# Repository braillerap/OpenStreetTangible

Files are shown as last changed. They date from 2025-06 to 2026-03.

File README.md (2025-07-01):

# OpenStreetTangible
OpenStreetTangible is a demonstration of what's possible in terms of accessible public transportation maps using OpenStreetTouch software, BrailleRAP, and various digital fabrication tools.

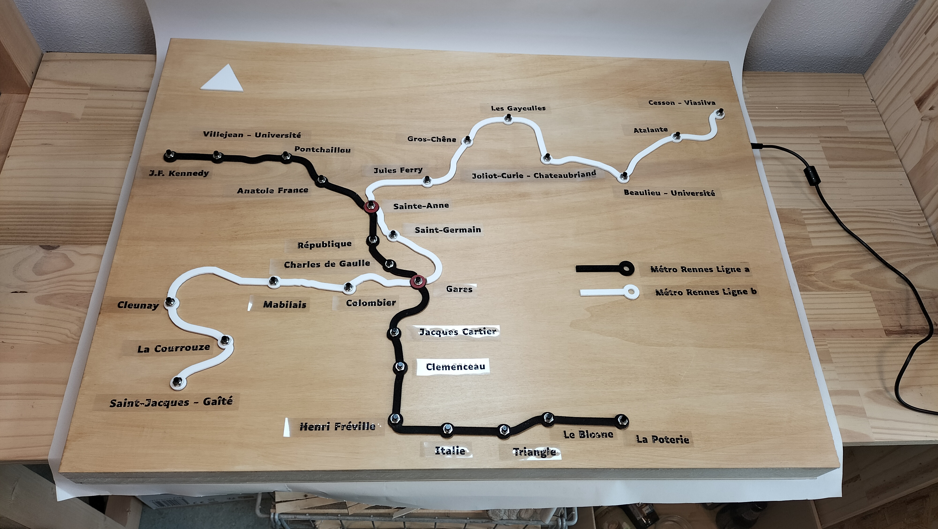
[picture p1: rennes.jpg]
Tangible map of Rennes Subway


It's a tactile, talking metro map of the city of Rennes in France, Britanny, designed for people with visual impairments.

To build this prototype, we used  [OpenStreetTouch](https://github.com/braillerap/OpenStreetTouch/releases) software to extract public transportation data and a [BrailleRAP](https://github.com/braillerap) to emboss stickers in Braille.

## Building manual
The building manual is available here [https://openstreettangible.readthedocs.io/en/latest/](https://openstreettangible.readthedocs.io/en/latest/)

Translations are availables here :

**en** 

**fr** 

## Contributions

### Translation
If you need the building manual in your locale language, we will be happy to add a new translation. Translation files are hosted on codeberg community translation platform and can be updated by anyone [weblate host on codeberg](https://translate.codeberg.org/engage/openstreettangible_buildingmanual/) for more information.

<a href="https://translate.codeberg.org/engage/openstreettangible_buildingmanual/">
Translation status
</a>

### New cities 
Feel free to open issues or pull requests ! We will be happy to review and merge your changes, especialy if you want to build a tangible transport map of your city.

## Funding

This project is funded through [NGI0 Entrust](https://nlnet.nl/entrust), a fund established by [NLnet](https://nlnet.nl) with financial support from the European Commission's [Next Generation Internet](https://ngi.eu) program. Learn more at the [NLnet project page](https://nlnet.nl/project/BrailleRAP).

[NLnet foundation logo](https://nlnet.nl)
[NGI Zero Logo](https://nlnet.nl/entrust)

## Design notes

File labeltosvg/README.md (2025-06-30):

# LABELTOSVG

This python script aim to build svg files suitables to make printed label stickers embossed with Braille on a BrailleRAP.

## Installation

you will need a python virtual env and install some python dependencies

```
python -m venv venv
source ./venv/bin/activate
pip install -r requirement.txt
```

## usage

To generate svg files for printer and BrailleRAP you will need a text files generated by [OpenStreetTouch](https://github.com/braillerap/OpenStreetTouch). for exemple here is the labels file for the Rennes subway map.

```
Métro Rennes Ligne a Direction Rennes (J.F. Kennedy) :
     La Poterie
     Le Blosne
     Triangle
     Italie
     Henri Fréville
     Clemenceau
     Jacques Cartier
  *  Gares
     Charles de Gaulle
     République
  *  Sainte-Anne
     Anatole France
     Pontchaillou
     Villejean - Université
     J.F. Kennedy

Métro Rennes Ligne b Direction Cesson-Sévigné (Viasilva) :
     Saint-Jacques - Gaîté
     La Courrouze
     Cleunay
     Mabilais
     Colombier
  *  Gares
     Saint-Germain
  *  Sainte-Anne
     Jules Ferry
     Gros-Chêne
     Les Gayeulles
     Joliot-Curie - Chateaubriand
     Beaulieu - Université
     Atalante
     Cesson - Viasilva

```
to generate svg files use the command :
```
python file2label.py <label txt file>
```

## Configuration
The script take account of the offset between our BraileRAP XL and a laser printer. During our cession, it appear that the BrailleRAP XL is very precise and reliable, the laser printer is not very accurate.

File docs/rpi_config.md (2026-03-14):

## Configuration du Raspberry PI 5
### Création de l'image système

Avec l'outil [Raspberry Pi Imager](https://www.raspberrypi.com/software/) installer la dernière version de **Raspberry PI OS** en version **lite** sur une carte SD.

vous devez activer une installation personnalisée avec les options suivantes

* Nom d'hote **subwaymap**
* creation d'un utilisateur **tactilmap** avec un mot de passe.
* activation de **ssh**.

```{note}
Pour terminer l'installation, vous aurez besoin de vous connecter au Raspberry PI par le réseau. De manière générale nous réalisons cette opération en connectant un câble ethernet, si vous souhaitez connecter le raspberry pi en wifi, vous devez configurer le wifi avant l'installation
```

Une fois toutes les options configurées, vous pouvez lancer la création de l'image sur la carte SD.

### Installation du système

* Connecter la carte shapeless_rp2040_40keys sur le Raspberry Pi avec un câble micro USB.
* Connecter le Raspberry Pi au réseau ethernet si besoin
* Brancher le câble USB micro d'alimentation du Raspberry PI
* Brancher la sortie audio du Raspberry PI sur un système audio avec un câble jack.

Une fois le Raspberry PI démarré, connectez-vous au Raspberry PI en ouvrant une console et en utilisant la commande :
```
ssh tactilmap@subwaymap.local
```
Le Raspberry PI vous demande alors le mot de passe associé au compte **tactilmap**. Le mot de passe a été configuré au moment de la création de l'image du système.

Ensuite à l'aide de l'outil **raspi_config** étendre la partition à l'ensemble de la carte SD et redémarrer le raspberry PI.
```
sudo raspi_config
```

Le Raspbery PI est désormais prêt pour l'installation des logiciels necessaires pour l'utilisation avec la carte tactile.

### Installation des logiciels

Connectez-vous au Raspberry PI :
```
ssh tactilmap@subwaymap.local
```

Installer les logiciels avec les commandes :
```
sudo apt update
sudo apt upgrade
sudo apt install git nano
sudo apt install cmake build-essential python3-dev
sudo apt install libportaudio2 libportaudiocpp0 portaudio19-dev

```

Installer la synthèse vocale **espeack-ng**
```
sudo apt install espeak-ng
```

### Carte Son
Le Raspberry PI 5 ne possède plus de sortie son au format JACK 3.5. Nous avons utilisé une carte son [Adafruit I2S - UDA1334A](https://learn.adafruit.com/adafruit-i2s-stereo-decoder-uda1334a). La qualité sonore est grandement améliorée par rapport à la carte son native des Raspberry 3 ou 4.

### Installation du logiciel speakerkeyboard

Le logiciel [speakerkeyboard](https://github.com/crocsg/speakerkeyboard) permet de déclencher la lecture d'un message en synthèse vocale lors de l'appui sur une touche du clavier. En utilisant la carte **shapeless_rp2040_40keys** il est possible de simuler l'appui sur une touche d'un clavier en appuyant sur un des boutons de la carte tactile.

```
cd /home/tactilmap
git clone https://github.com/crocsg/speakerkeyboard.git
cd speakerkeyboard
python -m venv venv
source ./venv/bin/activate
pip install -r requirement.txt
```

Le logiciel est utilisable uniquement en mode **root** dans la mesure ou nous utilisons le module python **keyboard** pour intercepter les évenements clavier.

Pour lancer le logiciel
```
sudo bash
cd /home/tactilmap/speakerkeyboard
source ./venv/bin/activate
python kspeaker.py
```

### Configurer les noms des stations

Pour réaliser la configuration, les boutons de la carte tactile doivent être branchés sur la carte **shapeless_rp2040_40keys** et la carte **shapeless_rp2040_40keys** doit être reliée en usb sur le Raspberry PI.

Lancer le logiciel
```
sudo bash
source ./venv/bin/activate
python kspeaker.py
```

Lors de l'appui sur un bouton de la carte tactile, le logiciel affiche le **code clavier**, le texte associé. Si un texte est associé à la touche, la synthèse vocale se déclenche et lit le texte en audio.

Pour configurer un message, arreter le logiciel avec `CTRL-C`, vous devez ensuite éditer le fichier **kspeaker.json** pour entrer le **code clavier** et le texte associé dans la section **messages**.

Le fichier **configuration.json** pour la carte tactile du métro de Rennes est donné ici a titre d'exemple.
```
{
    "device": "",
    "speed": 100,
    "volume": 40,
    "voice": "-",
    "sync":0,
    "messages": {
	"49":"J.F Kénnédy, ligne A",
	"5" :"Villejean Université, ligne A",
	"2" :"Pontchaillou, ligne A",
	"4" :"Anatole France, ligne A",
	"6" :"Sainte Anne, ligne A et B",
	"50":"République, ligne A",
	"7" :"Charles de Gaulles, ligne A",
	"3" :"Gares, ligne A et B",
	"45":"Jacques Cartier, ligne A",
	"44":"Clémenceau, ligne A",
	"46":"Henri Fréville, ligne A",
	"47":"Italie, ligne A",
	"38":"Triangle, ligne A",
	"48":"Le Blaune, ligne A",
	"37":"La poterie, ligne A",
	
	"20":"Saint Jacques Gaité, ligne B",
	"17":"La Courrouze, ligne B",
	"19":"Mabilais, ligne B",
	"22":"Saint Germain, ligne B",
	"24":"Jules Ferry, ligne B",
	"23":"Gros Chêne, ligne B",
	"25":"Joliot Curie  Chateaubriand, ligne B",
	"32":"Beaulieu université, ligne B",
	"9" :"Césson Via Silva, ligne B",
	"10":"Atalante, ligne B",
	"33":"Cleunay, ligne B",
	"31":"Colombier, ligne B",
	"34":"Les Gayeulles, ligne B"
    }
}
```
Vous pouvez remarquer que certains noms ont été modifiés pour mieux correspondre à la phonétique française et permettre une meilleure compréhension de la synthèse vocale. Notamment **Kennedy** a été transformé en **Kénnédy**, **Le Blosne** a été transfomé en **Le Blaune**.

### Lancement du logiciel au démarrage du système

Pour pouvoir utiliser la carte tactile de façon autonome, le logiciel **kspeaker** doit se lancer au démarrage du système. Pour installer le logiciel comme script système, utiliser la commande :

```
sudo bash
cd /home/tactilmap/speakerkeyboard
./install_service.sh
```

Une fois le logiciel installé en service système, vous pouvez l'arrêter en utilisant la commande :
```
sudo systemctl stop kspeaker
```

vous pouvez également le relancer avec la commande :
```
sudo systemctl start kspeaker
```

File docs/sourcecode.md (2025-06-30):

# Code source et mises à jour

Vous pouvez trouvez les fichiers de ce projet sur github [OpenStreetTangible](https://github.com/braillerap/OpenStreetTangible). En particulier :

* Les fichiers .stl d'impression 3d dans le repertoire `3dprint`.
* Les fichiers 3d au format .step pour les modifier avec **FreeCad** par exemple dans le repertoire `3dprint/CAD`.
* Les fichiers SVG pour la découpe laser dans le répertoire `lasercutfiles`.

La carte clavier est disponible ici avec l'ensemble des fichiers pour la production de carte (schéma, GERBER ...) [shapeless_rp2040_40keys](https://github.com/crocsg/shapeless_rp2040_40keys) dans le repertoire `hardware`.
Le firmware QMK pour la carte clavier est disponible au même endroit.

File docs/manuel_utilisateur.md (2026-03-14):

# Introduction
OpenStreetTangible est une démonstration de ce qu'il est possible de réaliser en terme de plan de transports en communs accessible à l'aide du logiciel OpenStreetTouch, d'une BrailleRAP et de divers outils de fabrication numérique.

C'est un plan de métro tactile et parlant de la ville de Rennes qui est destiné aux personnes déficientes visuelles.  

Ce prototype , réalisé  avec le  programme  [OpenStreetTouch](https://github.com/braillerap/OpenStreetTouch/releases) et l’embosseuse braille opensource [Braillerap](https://github.com/braillerap), est une preuve de concept qui peut être déclinée pour n’importe quelle autre ville dans le monde.

Il associe un plan en relief du métro avec des boutons pour chaque station permettant de vocaliser leur nom. Il est complété par des étiquettes en braille pour chacune d’elle, en surimpression du nom écrit de manière contrastée et en gros caractère.

<iframe width="560" height="315" src="https://www.youtube.com/embed/g61iP3ccKi4?si=aKcSwKW6WduUQhPF" title="YouTube video player" frameborder="0" allow="accelerometer; autoplay; clipboard-write; encrypted-media; gyroscope; picture-in-picture; web-share" referrerpolicy="strict-origin-when-cross-origin" allowfullscreen>
</iframe>

Le  programme OpenStreetTouch permet non seulement d’extraire des plans de ville  mais aussi d’en extraire les données de transport (bus/car, tramway, métro, train, train interurbain, monorail, ferry, funiculaire) depuis OpenStreetMap, fonction que nous utilisons ici.

Les fichiers numériques ainsi récupérés permettent de produire des objets physiques avec des machines à commande numérique que l’on trouve notamment dans les fablabs.

Les personnes déficientes visuelles s’appuient principalement sur le toucher et la synthèse vocale pour compenser le sens de la vision. Elles peuvent alors se faire des représentations mentales de leur environnement et faciliter leur locomotion.

Compte tenu du panel très large que représente la déficience visuelle entre une vision totalement inexistante et une vue altérée, ainsi que les sensibilités et capacités de chacun que ce soit pour lire le braille ou préférer une information vocalisée, il nous a semblé pertinent de multiplier l’accessibilité en proposant 3 possibilités pour accéder à  l’information (synthèse vocale, écriture en gros caractère, et écriture en braille). 

En répondant aux exigences des uns et des autres à travers un seul objet, ce type de plan pourrait parfaitement avoir sa place dans une station de métro ou un centre de locomotion pour déficients visuels.

Il est composé d’un panneau de bois de 80 x 60 cm sur lequel les deux lignes du métro de Rennes , découpées à la laser,  y sont collées. L’une se caractérise par un toucher rugueux spécifique au papier de verre tandis que l’autre est très lisse grâce au PMMA,  elles sont ainsi immédiatement dissociables au toucher. Une légende en bas à gauche du plan est également présente afin d’identifier chacune des deux lignes. 

Chaque station est représentée par un bouton que l’on peut cliquer pour vocaliser son nom.  Une étiquette est aussi associé à chacune d’elle avec son nom écrit en braille en surimpression du nom écrit en noir et gros caractère.

Pour l'impression des étiquettes, nous avons utilisé la police *Luciole*, spécialement crée pour les mal voyants. Cette police est disponible ici [https://www.luciole-vision.com](https://www.luciole-vision.com). La police *Luciole* est disponible sous licence libre CC BY 4.0.

Le matériau utilisé pour les étiquettes sont des feuilles transparentes pour impression laser. La transparence permet d'imprimer les étiquettes en contraste élevé. Ces feuilles fonctionnent correctement pour l'embossage Braille avec la BrailleRAP.

L’écriture braille ne permet pas de modifier la taille des caractères puisqu’il est indispensable de respecter un écart standard entre les points qui composent chaque caractère afin de rester lisible. C’est une contrainte majeure dans la mesure où le braille prend nécessairement une place importante et écarte d’emblée la réalisation de petits formats si l’on souhaite avoir l’ensemble de l’information sur un même support.

Cette version utilise un nouveau moteur de synthese vocale [piper](https://github.com/OHF-Voice/piper1-gpl). La synthèse est nettement améliorée, par contre **piper** utilise beaucoup plus de ressources CPU pour la synthèse vocale et necessite une Raspberry PI 5 pour obtenir une installation réactive et confortable.

Le Raspberry PI 5 ne possède plus de sortie son au format JACK 3.5. Nous avons donc utilisé une carte son [Adafruit I2S - UDA1334A](https://learn.adafruit.com/adafruit-i2s-stereo-decoder-uda1334a). La qualité sonore est grandement améliorée par rapport aux cartes son natives des Raspberry 3 ou 4.

# Financement

Ce projet est financé grace à [NGI0 Entrust](https://nlnet.nl/entrust), un fond créé par [NLnet](https://nlnet.nl) avec le support du programme  [Next Generation Internet](https://ngi.eu) de la Commision Européene. Plus d'informations ici [NLnet project page](https://nlnet.nl/project/BrailleRAP).

[ 
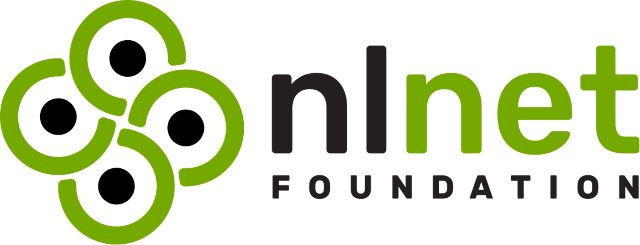
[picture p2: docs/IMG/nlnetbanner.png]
    
](https://nlnet.nl) 
[
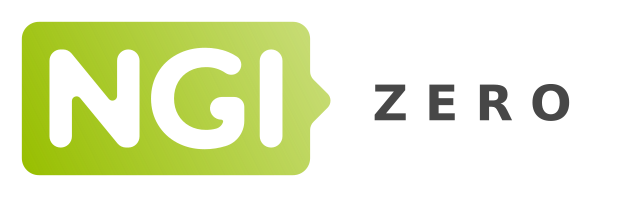
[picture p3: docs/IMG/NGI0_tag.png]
    
](https://nlnet.nl)

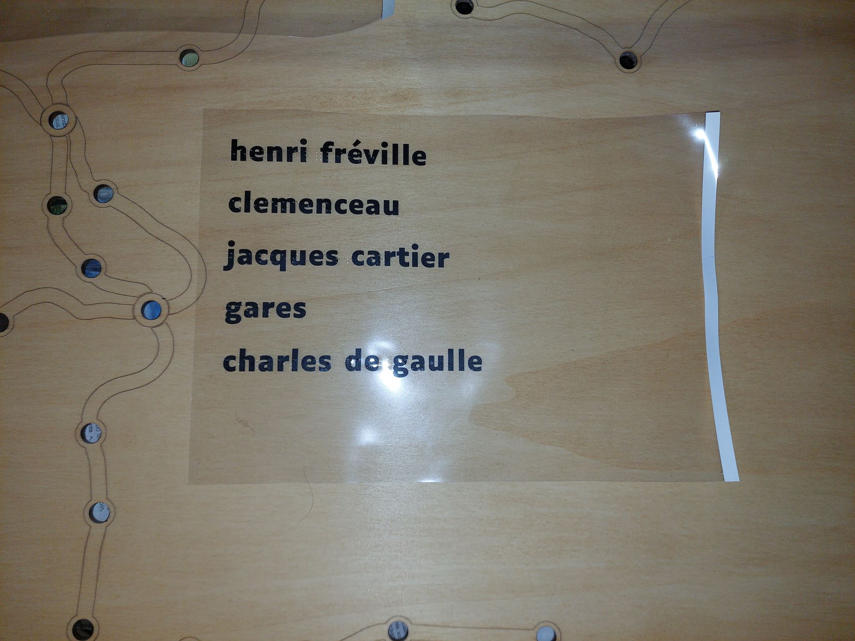
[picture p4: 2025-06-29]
docs/IMG/label1.jpg

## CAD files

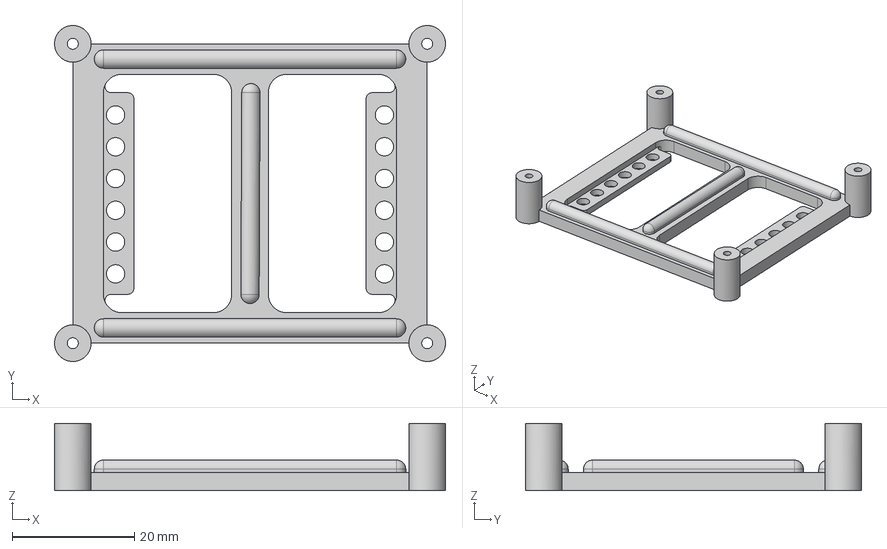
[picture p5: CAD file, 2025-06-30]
3dprint/CAD/support_rpi v3.step
64.0 x 55.0 x 11.0 mm

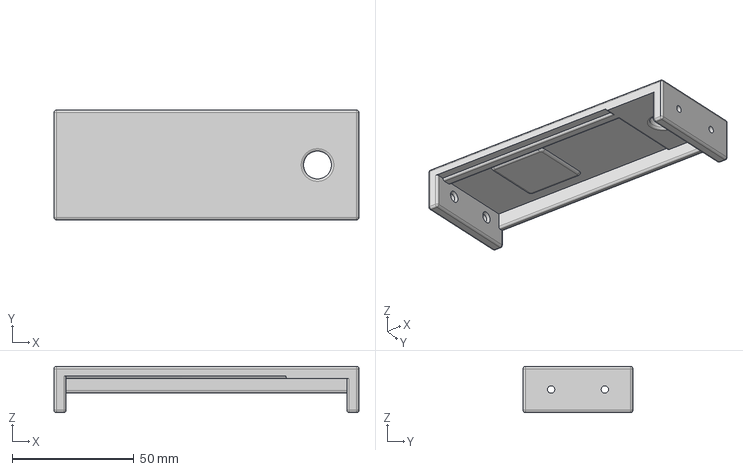
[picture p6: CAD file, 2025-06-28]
3dprint/CAD/subwaycommande v3.step
125.0 x 45.0 x 19.0 mm

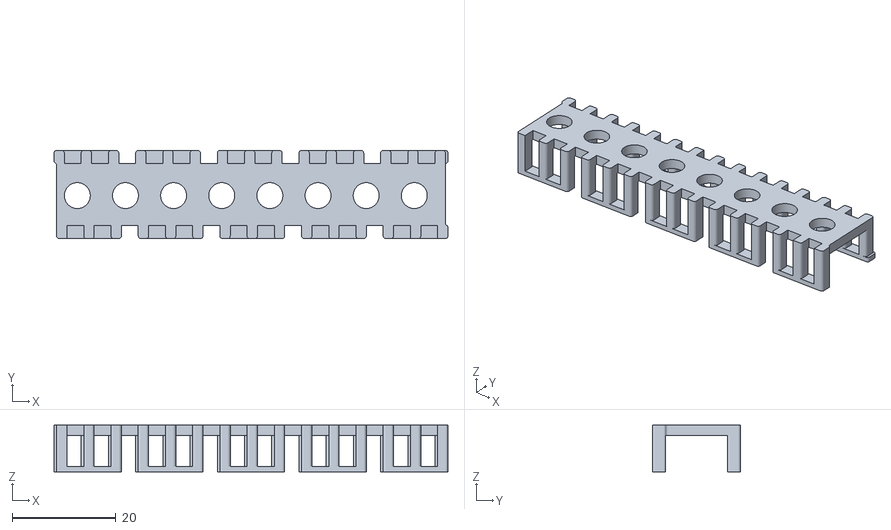
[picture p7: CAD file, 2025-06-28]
3dprint/chemin_cable.stl
76.0 x 17.0 x 9.00

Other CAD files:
3dprint/support_rpi.stl
3dprint/CAD/chemin_cable v4.step
3dprint/subwaycommande.stl

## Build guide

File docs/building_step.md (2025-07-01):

# Étapes de fabrication

## Liste du matériel

### Outillage
* Une [BrailleRAP](https://github.com/braillerap/BrailleRap)
* Découpe laser
* imprimante laser (vous pouvez utiliser une imprimante jet d'encre en utilisant les feuilles transparentes adaptées)
* Perceuse
* Fer à souder
* Multimètre
* Serre joints ou grosses pinces

### Consommables

* Soudure pour électronique
* fils de cablage
* colle cyanoacrylate pour coller plexi sur bois
* colle à bois
* colle en spray (non repositionnable)
* bombe de peinture noire
* bombe de peinture rouge

### Réalisation du plan

* papier de verre (grammage 120)
* 2 plaques de contreplaqué de peuplier de 5mm d'épaisseur de 80 cm x 60cm
* 1 plaque de contreplaqué de peuplier 3mm pour découpe d’une ligne de métro (format adapté à la taille de la découpeuse laser) et légende
* 1 plaque de PMMA blanc 3mm pour découpe d'une ligne de métro (format adapté à la taille de la découpeuse laser) et légende
* 1 tasseau de 53,5cm (section 3x5cm)
* 1 tasseau de 41cm (section 3x5cm)
* 2 tasseaux de 80 cm (section 3x5cm)
* ~10 Feuilles transparentes pour impression laser pour les etiquettes de stations en noir et en Braille
* 8 x inserts M6 x23mm
* 8 x Vis M6

### Electronique

* Une raspberry pi version 2 ou supérieure 1GO de RAM est largement suffisant. Une Raspberry PI zero est surement utilisable mais il faut lui ajouter une sortie audio
* carte clavier [shapeless_rp2040_40keys](https://github.com/crocsg/shapeless_rp2040_40keys)
* 2 cables micro USB, 1 pour l'alimentation du Raspberry, 1 pour la liaison shapeless_rp2040_40keys / raspberry pi
* 30 boutons poussoir à souder, fixation par écrou (autant de boutons que de stations + la légende)
* fils de cablage pour connecter les boutons à la raspi (deux couleurs différentes, pour dissocier chaque ligne)
* connecteurs dupont femelle 2 fils pour la connexion des boutons à la carte shapeless_rp2040_40keys
* ampli audio avec entrée mini jack
* cable mini jack audio
* 1 Haut parleur 3~5 W
* Embase Alimentation jack 2.5mm
* Alimentation 12V 6A avec connecteur Jack 2.5mm

## Partie logicielle : Open Street Touch & Inkscape

### Extraction des données de lignes de transport avec OpenStreetTouch
* Installer OpenStreetTouch et suivre le tutoriel associé pour extraire les données de transports qui vous intéressent.
 (https://openstreettouch.readthedocs.io/fr/latest/manuel_utilisateur.html) 

 Nous n'utiliserons pas l'option "polygones pour tracés de lignes", de manière a pouvoir manipuler les entités de façon fines avec le logiciel Inkscape.

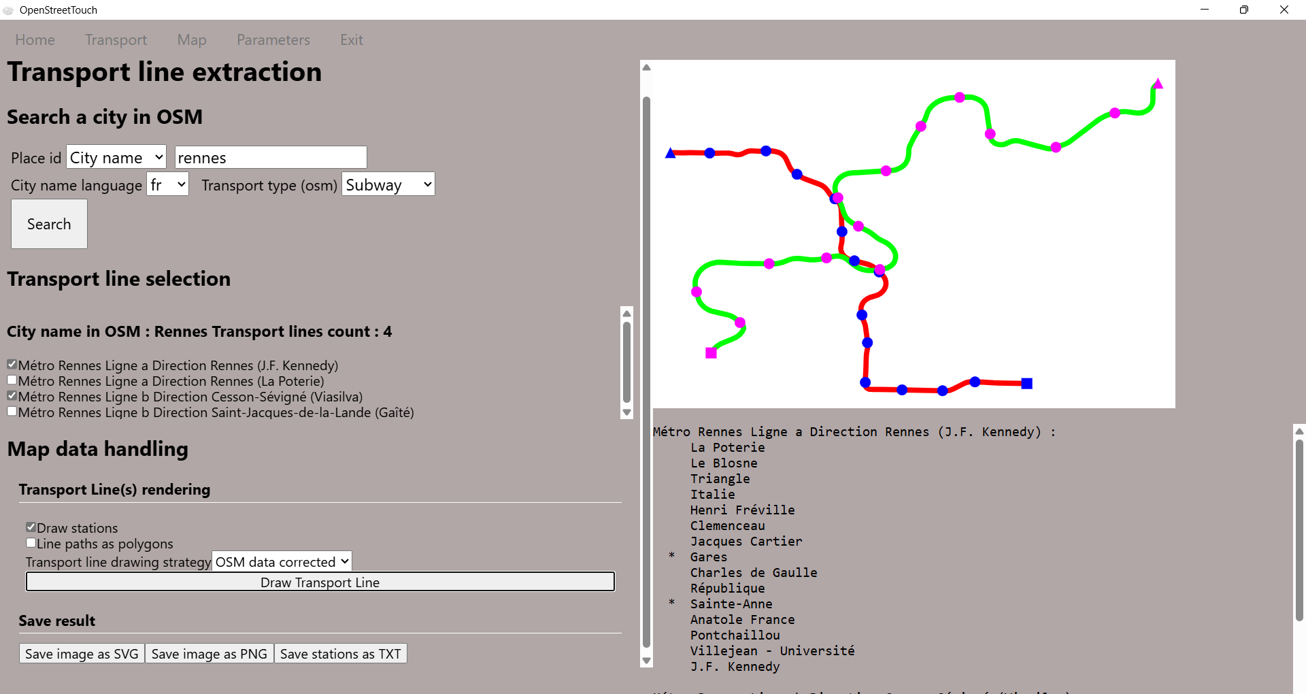
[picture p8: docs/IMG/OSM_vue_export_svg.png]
Vue de l’interface OpenStreetTouch


* Dans le cas de la ville de Rennes, les lignes ont le même tracé dans les deux sens de circulation. Nous avons donc sélectionné chaque ligne une seule fois.
* Extraire l’ensemble des lignes de transport souhaitées sur un seul SVG. Ce fichier servira à réaliser un fichier pour la gravure du fond et la découpe des tracés de lignes.

* Extraire également le nom des stations pour chacune des lignes avec le bouton "Enregistrer les stations en TXT"

Le fichier d'extraction SVG obtenu est le suivant

###  Transformation des fichiers avec Inkscape
Le SVG issu d'OpenStreetTouch doit être modifié avec un logiciel de dessin vectoriel comme Inkscape (logiciel libre et gratuit).

#### Mise à l'échelle du plan
*  Ouvrir le svg de l'ensemble des lignes avec Inkscape et mettre le SVG à l’échelle du plan choisi (redimensionner le document à la taille souhaitée)

  Fichier>propriétés du document 
  
  Ajuster la taille du document aux dimensions souhaitées (ici 800 x 600 mm)
  
  Sélectionner ensuite l'ensemble des lignes (CTL+A) et agrandir à la taille souhaitée pour s'ajuster au format du document. Penser à garder un peu de marge sur les bords (dans notre cas 50 mm).
  Ce fichier servira ensuite à la réalisation de :

  * Un fichier pour la gravure et le perçage de la plaque de fond. La gravure permettra d'avoir un repère pour le collage des lignes. Les perçages permettront le passage des boutons qui sont vissés sur les lignes des stations.
  * Plusieurs fichiers pour la découpe de chaque ligne de métro.

####  Mise en forme du réseau

Pour des raisons esthétiques et pratiques nous avons effectué les modifications suivantes :

* Les débuts et fin de lignes ont été remplacés par des cercles.
* Les cercles des stations sont redimensionnés à 15 mm de diamètre.
* La largeur des tracés de lignes est défini à 8 mm.
* Nous avons fusionné les stations avec correspondance. Parce que cela permet d'avoir un tracé de ligne plus évident quand on le suit au doigt. Pour la ville de Rennes, ce choix est assez évident. Cela permet également de distinguer les stations en correspondance avec un matériau, donc un touché différent.
* A proximité des stations en correspondance, nous avons espacé les lignes de transport pour obtenir un tracé moins ambigü au niveau des correspondances et conserver une largeur de ligne de 8mm.
* Quelques stations ont été légèrement déplacées pour faciliter l'étiquetage Braille, cela ne change pas la géographie du réseau, cela permet juste d'éviter d'avoir des étiquettes trop proches les unes des autres.

Le fichier svg résultat est le suivant
Le fichier svg résultat est le suivant
*Fichier SVG "rennes_metro_worked2.svg" après ajustements pour la mise en forme du réseau*

#### Préparation du fichier pour la gravure et le percage de la plaque de fond

A partir du fichier **rennes_metro_worked2.svg** nous avons réalisé les opérations suivantes avec inkscape :

* Transformation des lignes en contour en respectant la largeur de trait de 8mm en sélectionnant chaque ligne et en utilisant la fonction `Path/Object to path`.
* Pour chaque station, ajout d'un cercle qui correspondra au percage de la station pour faire passer le bouton poussoir (trou de 10.7 mm)
* Transformation des stations en chemins en sélectionnant les cercles exterieures des stations et en utilisant la fonction `Path/Object to path`.
* Les lignes et les stations sont ensuite fusionnées en sélectionnant les stations et les lignes  et en utilisant la fonction `Path/Union`.
* Les lignes sont découpées au niveau des stations en correspondances avec la fonction `Path/difference`.

Pour réaliser la plaque de fond, les lignes noires correspondent à la gravure pour repérer la position des lignes, les lignes rouges correpondent aux découpes pour les boutons poussoirs.

Le fichier svg résultat est le suivant
Le fichier svg résultat est le suivant
*Fichier SVG  "rennes_subway_fond.svg" préparé pour la découpe laser pour procéder à la gravure et le perçage de la plaque de fond*

#### Préparation des fichiers pour la découpe des lignes

A partir du fichier *rennes_metro_worked2.svg* nous avons réalisé les opérations suivantes avec inkscape :

* Transformation des lignes en contour en respectant la largeur de trait de 8mm en sélectionnant chaque ligne et en utilisant la fonction `Path/Object to path`.
* Pour chaque station, ajout d'un cercle qui correspondra au percage de la station pour fixer le bouton poussoir (trou de 7 mm)
* Transformation des stations en cercle en sélectionnant les cercles exterieures des stations et en utilisant la fonction `Path/Object to path`.
* Les lignes et les stations sont ensuite fusionnés en sélectionnant les stations et les lignes  et en utilisant la fonction `Path/Union`.
* Les lignes sont découpées au niveau des stations en correspondances avec la fonction `Path/difference`.

Pour les lignes de transport, les lignes noires correspondent à des découpes extérieures, les lignes rouges correpondent aux découpes pour les boutons poussoirs. Pour chaque lignes on regroupe les différentes parties pour optimiser l'utilisation du matériau.

Les fichiers svg résultats sont les suivants :

Pour la ligne A
Le fichier de découpe de la ligne A
*Fichier SVG de découpe de la ligne A*

Pour la ligne B
Le fichier de découpe de la ligne A
*Fichier SVG de découpe de la ligne B*

#### Réalisation à l'aide de la découpe laser

En utilisant le logiciel de la découpe laser, nous avons réalisé la plaque de fond en marquant les tracés en noir et en découpant les tracés en rouge sur une plaque de contreplaqué peuplier 5mm.

Les lignes A et B sont ensuite découpées en découpant les tracés rouges puis les tracés noirs. Chaque ligne est découpée dans un matériau différent, du PMMA blanc 3mm et du contreplaqué peuplier 3mm.

Pour la ligne en contreplaqué peuplier, nous avons utilisé le même fichier de découpe pour découper les lignes dans du papier de verre 120.

```{note} 
Ne pas enlever le plastique protecteur du PMMA. Le plastique de protection sera retiré juste avant le collage.
```

Une fois les éléments découpés, on effectue un test de mise en place sans collage.

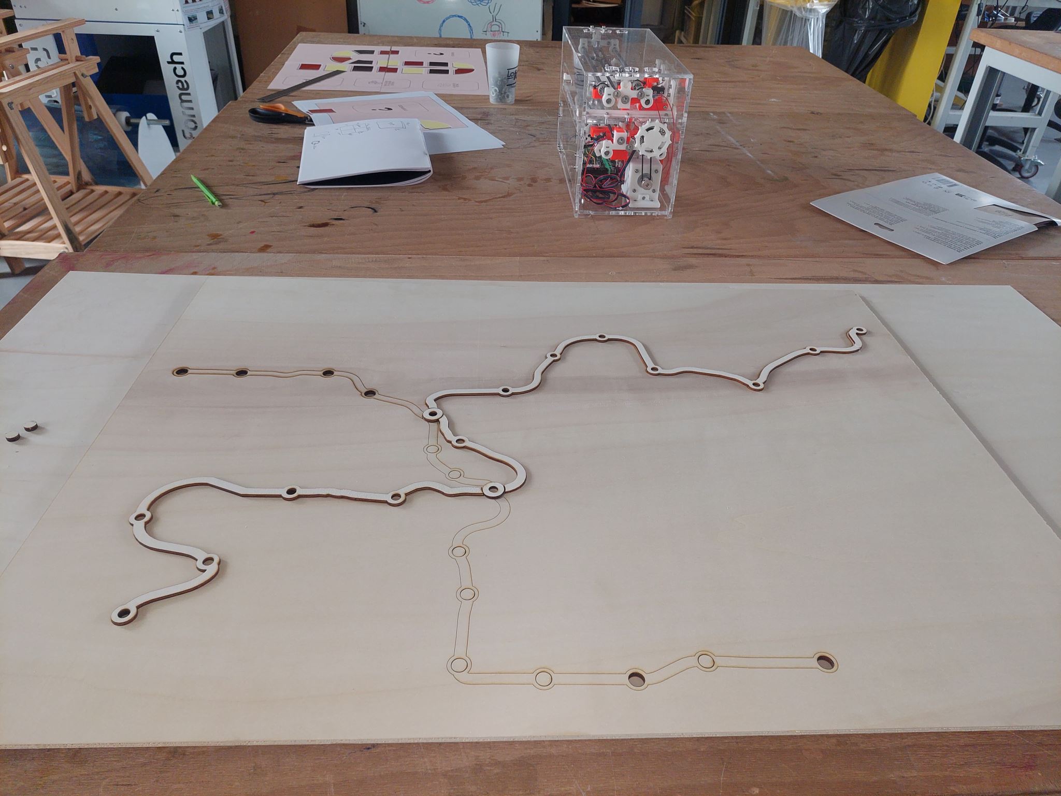
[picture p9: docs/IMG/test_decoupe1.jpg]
test des différents éléments découpés une seule ligne

*Vérification de la concordance des découpes de ligne avec la gravure*

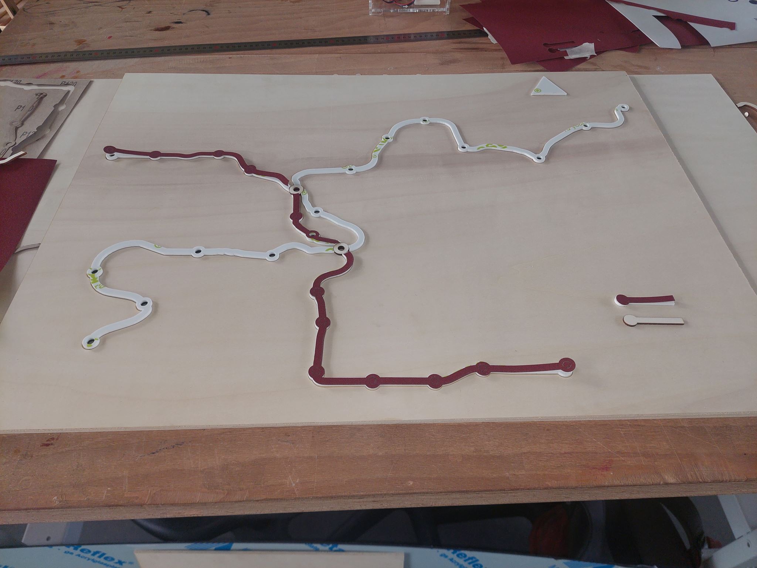
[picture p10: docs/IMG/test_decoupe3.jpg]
test des différents éléments découpés les deux lignes avec le papir de verre

*Vérification de la concordance des découpes de ligne avec la gravure*¨

### Fichier 3D à imprimer

Imprimer en PLA ou PETG :

* Panneau de fixation de l'embase d'alimentation **subwaycommande.stl**.
* 1 ou 2 passe cable pour organiser les cables **chemin_cable.stl**.
* 1 Support de Raspberry PI **support_rpi.stl**.

```{note} 
Les fichiers STL pour l'impression se trouvent dans le repertoire 3dprint.
```

### Préparation des étiquettes

La difficulté pour la réalisation des étiquettes est d'aligner suffisamment bien l'impression, en gros caractères avec l'embossage Braille pour gagner de la place.

Pour réussir à aligner correctement l'impression et l'embossage, nous avons utilisé le script python dans le repertoire `labeltosvg`, ce script prend en entrée un fichier texte contenant une série de lignes à imprimer et génère une série de fichiers SVG numérotés pour l'impression standard et pour l'embossage sur BrailleRAP. 

Pour un numéro particulier, le fichier "xxxxxx.printer.svg" devra être imprimé avec une imprimante. Le fichier "xxxxxx.brap.svg" devra ensuite être embossé sur la BrailleRAP à l'aide du logiciel [DesktopBrailleRAP](https://github.com/braillerap/DesktopBrailleRAP).

Nous avons utlisé ce script python avec le fichier .txt des stations de transport généré par [OpenStreetTouch](https://github.com/braillerap/OpenStreetTouch)

Un exemple de fichier SVG pour l'impression
Un exemple de fichier SVG pour l'impression

```{note} 
Les fichiers SVG pour la réalisation des étiquettes se trouvent dans le repertoire labels.
```

#### Réalisation des étiquettes
Ouvrir un des fichiers préparé à l'aide de `labeltosvg` avec inkscape et l'imprimer sur l'imprimante laser.

Capture d'écran d'un fichier d'étiquettes dans Inkscape.
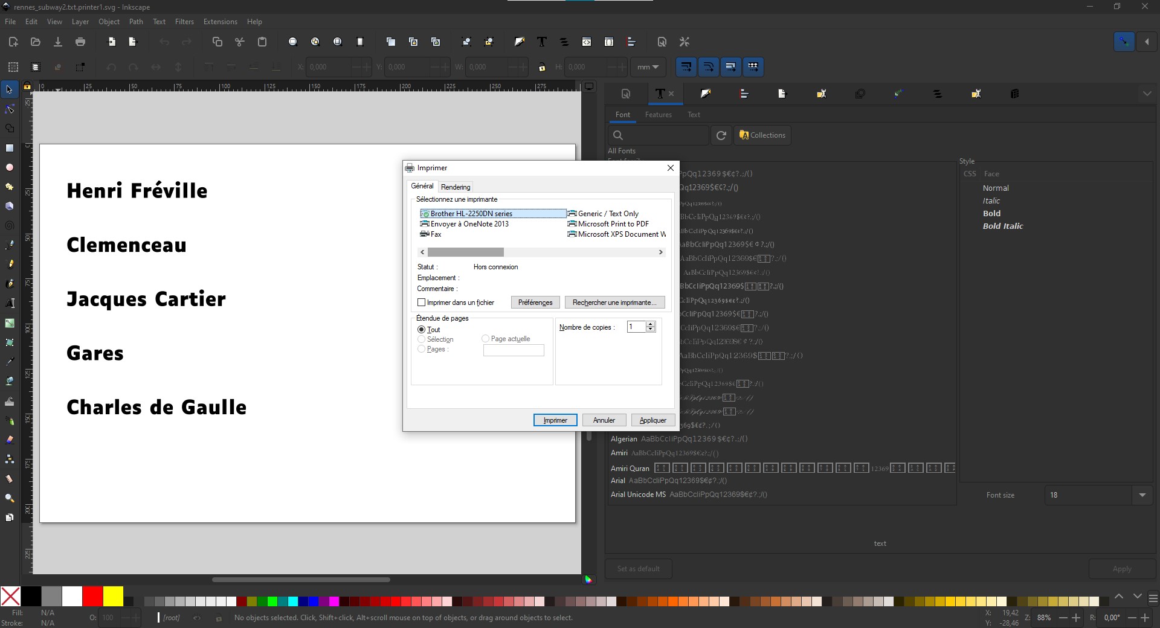
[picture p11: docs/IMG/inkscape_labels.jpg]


Insérer la feuille préalablement imprimé dans la BrailleRAP, puis importer le fichier SVG correspondant avec DesktopBrailleRAP, et le positioner en 0,0. Puis lancer l'impression sur la BrailleRAP pour obtenir le Braille par dessus l'impression en noir. 

Capture d'écran du même fichier d'étiquettes dans DesktopBrailleRAP.
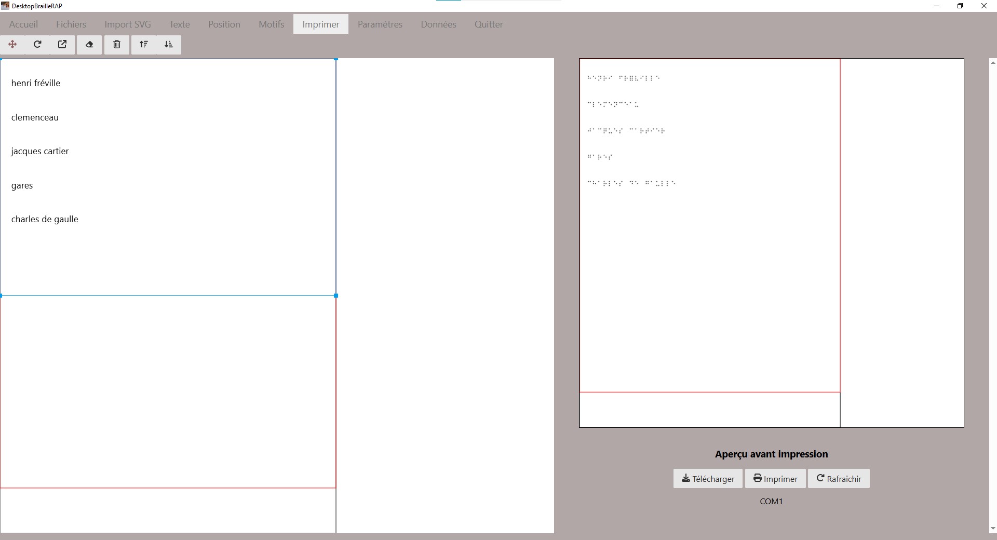
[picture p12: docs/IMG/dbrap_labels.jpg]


#### Découpe des étiquettes
- Découper ensuite les étiquettes ligne par ligne de préférence à l’aide d’un massicot sinon cutter ou ciseaux.
- Finaliser la découpe pour les séparer verticalement à l’aide d’un cutter ou de ciseaux en laissant toujours la même marge en début de mot et à la fin si possible.

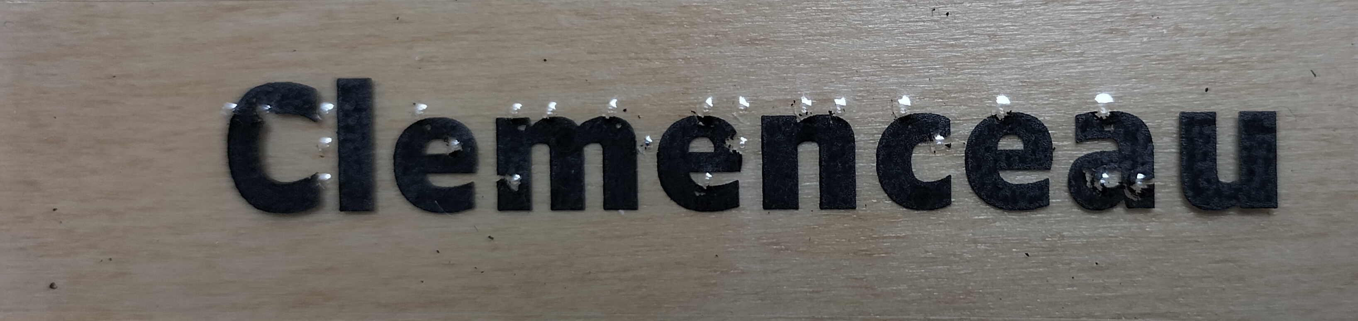
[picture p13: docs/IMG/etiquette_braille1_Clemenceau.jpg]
Etiquette imprimée en caractère noir avec surimpression braille

*Etiquette pour la station Clémenceau*

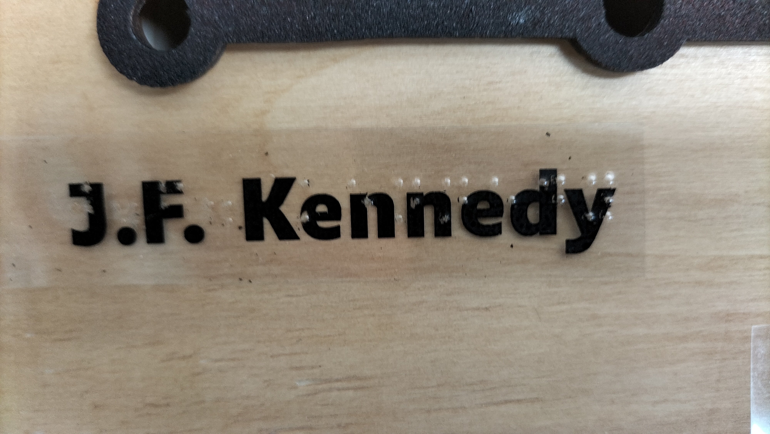
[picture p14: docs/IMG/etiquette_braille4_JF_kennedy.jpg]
Etiquette imprimée en caractère noir avec surimpression braille

*Etiquette pour la stationJ.F.Kennedy*

## Fabrication du plan de métro avec son chassis

### Peinture

Pour augmenter les contrastes, les lignes en papier de verre sont peintes en noir, les stations de correspondance sont peintes en rouge.

* Peindre à la bombe de couleur noire la ligne en papier de verre.
* Peindre à la bombe rouge les deux stations de correspondances

### Collage du papier de verre sur la ligne A

Coller la ligne A découpée dans le papier de verre sur sa ligne correspondante en bois avec de la colle à bois.

### Préparation du chassis du plan
#### Assemblage du cadre

* Mettre le plan 80 X 60 cm face gravée contre une table (propre !).

* Placer les tasseaux découpés à la bonne taille sur le cadre de la plaque. Dessiner au crayon à papier leur contour pour bien avoir le repère au moment du collage.

* Coller les tasseaux avec la colle à bois et les maintenir en place avec des pinces ou des serre-joints. Pour ne pas faire de marquage ou déformer les tasseaux avec les pinces et étaux, ajouter des plaques de protection entre le tasseau et la pince de serrage.
Procéder en plusieurs étapes si nécessaire en laissant sécher un minimum avant d'enlever les pinces et les serre-joints.

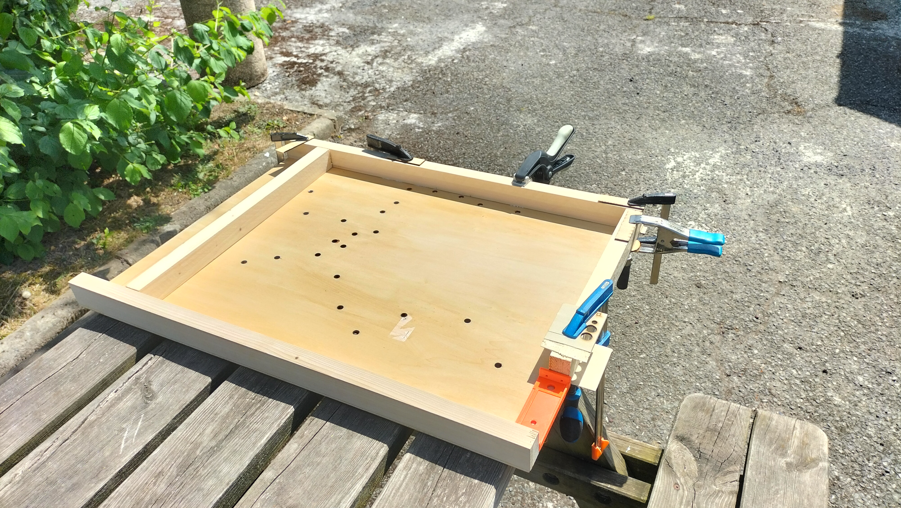
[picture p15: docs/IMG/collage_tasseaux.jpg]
Collage tasseaux

*Collage tasseaux*

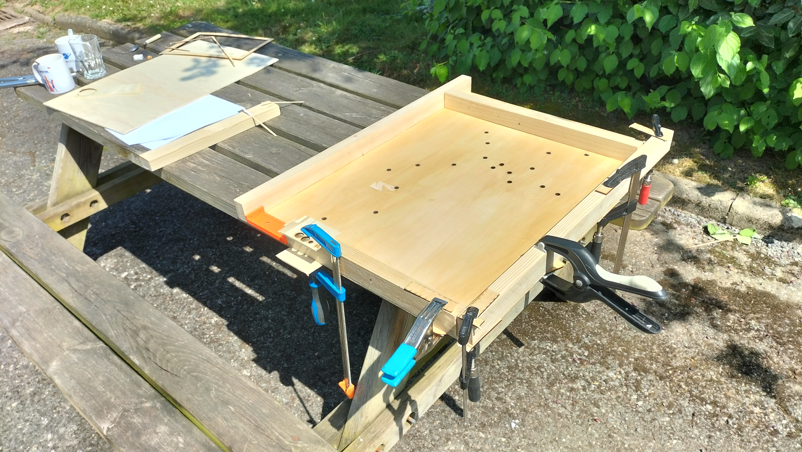
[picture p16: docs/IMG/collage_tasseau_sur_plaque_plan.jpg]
Collage tasseaux avec plaques de protection

*Collage tasseaux avec plaques de protection*

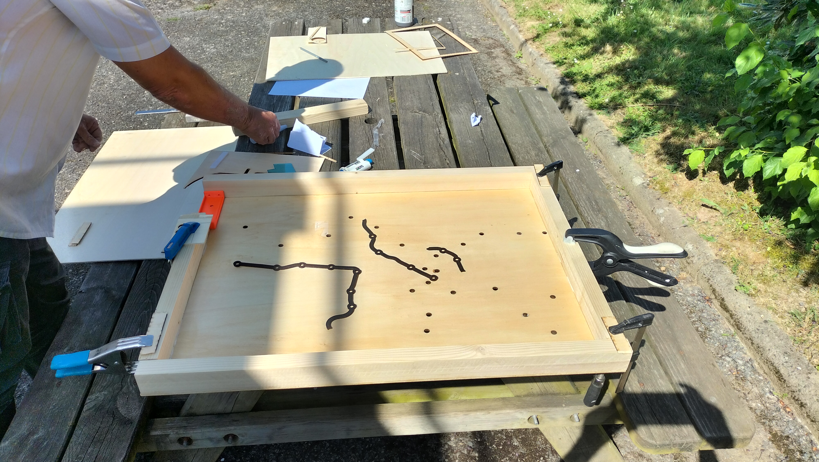
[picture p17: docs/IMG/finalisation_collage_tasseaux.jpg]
Finalisation collage tasseaux

*Finalisation collage tasseaux*
|

#### Préparation plaque socle pour refermer le boîtier

- Placer la plaque de 80 x 60 cm sur le chassis pour refermer la boite , la maintenir avec du scotch de peintre
- Mettre une marque au scotch sur le foret de 6mm pour déterminer la profondeur du perçage
- Percer 8 trous de 6mm de diamètre pour ajouter les inserts (1 à chaque coin et 1 entre chaque extrémité) traversant la plaque et les tasseaux de seulement qqs mm
- Percer à l'aide d'une perceuse les 8 trous à l'emplacement des inserts
- Enlever la plaque qui referme le boitier
- Changer le foret de 6 pour un foret de 8mm  (diamètre de perçage pour inserts), mettre une marque au scotch pour déterminer la profondeur de perçage (longueur insert - épaisseur plaque, soit ici 23-5=17mm)
- Percer chaque trou dans les tasseaux aux emplacement pré troués avec le foret de 6
- Insérer les inserts dans chaque trou et finaliser leur fixation avec avec un marteau ou maillet en faisant attention de ne pas les endommager , mettre une protection si nécessaire sur l'insert pour éviter que le marteau ne le déforme
- Vérifier que le boitier se referme en insérant les vis à leurs emplacements respectifs

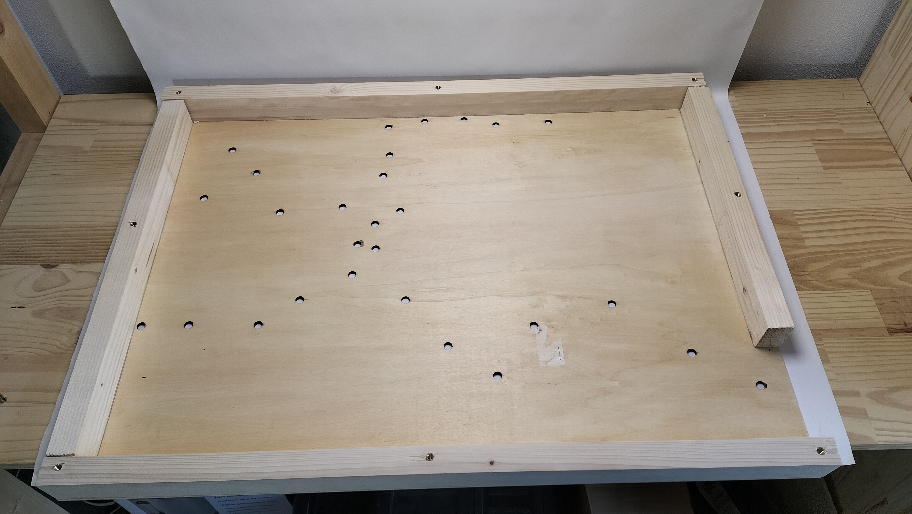
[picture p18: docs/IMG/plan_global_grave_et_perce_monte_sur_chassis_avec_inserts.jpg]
Plan global gravé et percé monté sur chassis avec inserts ajoutés pour le refermer par dessous

*Plan global gravé et percé monté sur chassis, avec inserts ajoutés pour le refermer par dessous*

#### Ponçage chassis
Avec une cale à poncer et papier de verre de 80, poncer les côtés afin qu'ils soient lisses et qu'ils tombent à fleur de la plaque du plan de métro

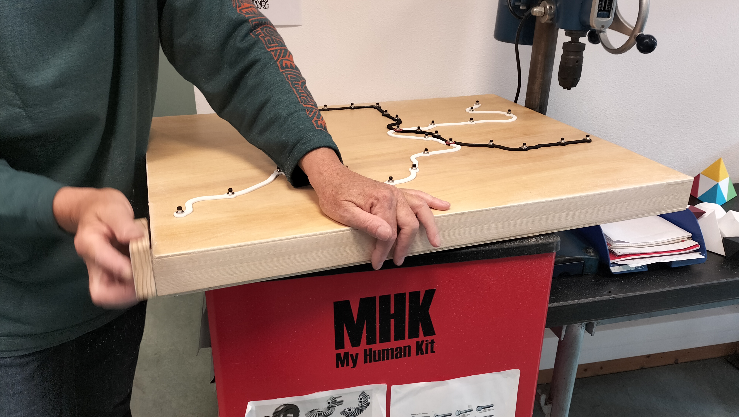
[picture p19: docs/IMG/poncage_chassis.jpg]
Ponçage du chassis

*Ponçage du chassis*

#### Vernissage du plan et du chassis
Vernir le plan de métro démonté du chassis et vernir aussi le chassis extérieur (côté et fond démonté afin de pouvoir le démonter ultérieurement) afin qu'il soit facilement lavable et plus résistant.

### Vérification de l'assemblage avant le collage des lignes de métro
- Positionner les éléments des deux lignes pour vérifier que tous les éléments sont présents et correspondent bien au tracé de repérage.

### Collage des lignes de métro et des stations de correspondance

* Coller les deux lignes de métro découpées à la laser sur le plan

* Coller chacune des lignes en vous repérant à la gravure. Utiliser la colle à bois pour la ligne A en peuplier et la colle cyano pour la ligne B en PMMA (enlever la protection sur la face qui sera collée juste avant d’appliquer la colle . 

* Coller les cercles correspondant aux stations de correspondance ici peintes préalablement à la bombe de peinture rouge.

## Montage du circuit électronique
### Préparation des boutons
- Étamer les boutons
- Mesurer la longueur de fil nécessaire entre chaque emplacement de bouton (trous des stations) jusqu'à l'emplacement de la carte clavier. Enlever la longueur de fil des fils des connecteurs pour avoir la bonne longueur. Prévoir quelques cm de plus
- Souder le fil intermédiaire (rallonge) entre le connecteur et le bouton comme sur cette photo en ajoutant de la gaine thermo sur les connections à la soudure

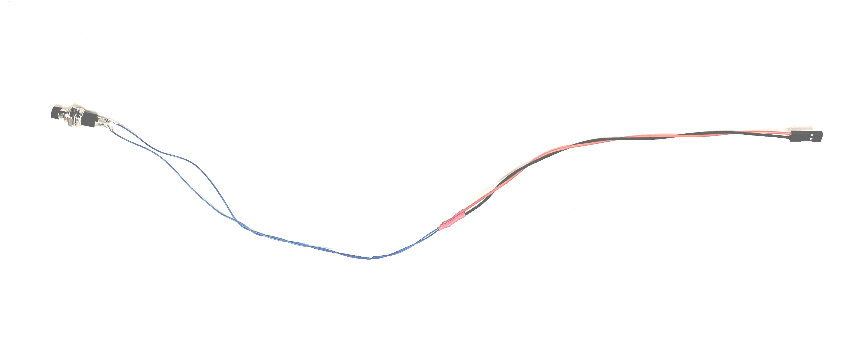
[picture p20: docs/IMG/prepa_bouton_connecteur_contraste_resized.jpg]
Préparation d'un bouton avec le fil de rallonge et le connecteur

*Bouton soudé avec le fil de rallonge et le connecteur*

- Préparer l'ensemble des boutons pour une ligne pour commencer en s'assurant d'avoir la même couleur de fil pour tous les boutons de cette ligne. On prendra une autre couleur pour la 2 e ligne.
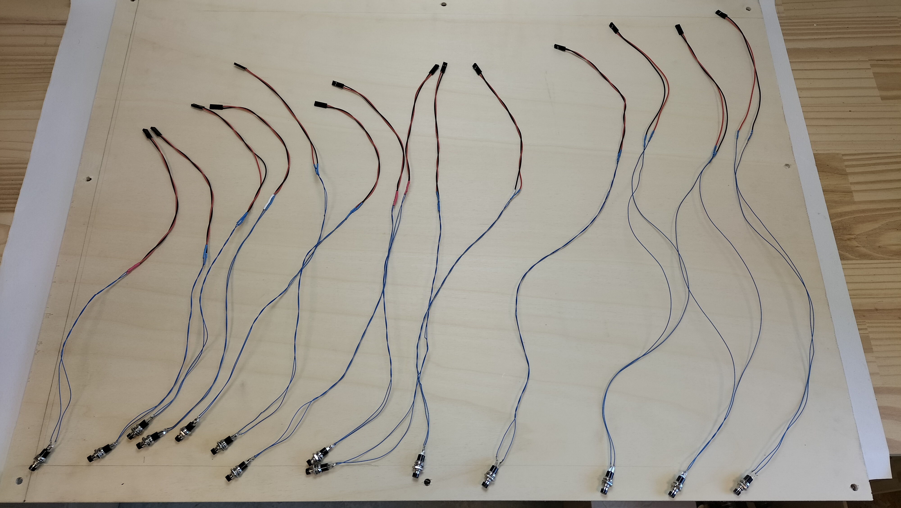
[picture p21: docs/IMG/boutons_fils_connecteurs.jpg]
Préparation de l'ensemble des boutons avec le fil de rallonge et connecteur

*Ensemble des boutons péparé pour une ligne classé par ordre de dimension*

### Montage des boutons sur le plan
- Insérer la rondelle sur le bouton pour qu'elle se trouve sous la plaque. Insérer ensuite le bouton avec sa rondelle par dessous et le fixer à la main avec l'écrou sur le dessus de la plaque(sans serrer avec une clé pour commencer)
- Procéder ainsi pour tous les boutons de l'ensemble de la ligne

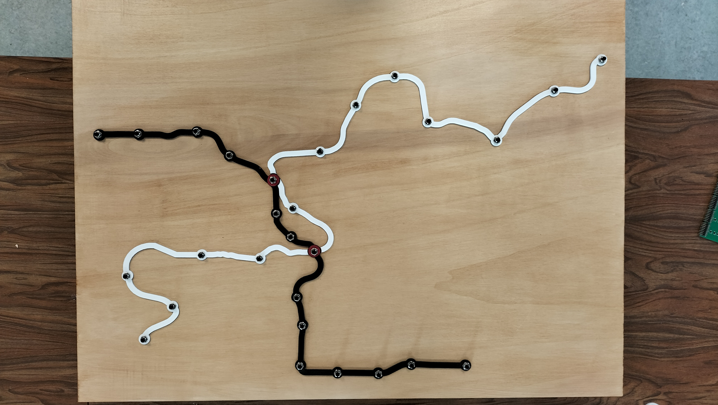
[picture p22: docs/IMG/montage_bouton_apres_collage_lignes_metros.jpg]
Montage des boutons sur le plan


### Pré-positionnement des étiquettes et vérification de l'ensemble des éléments
- Positionner chaque étiquette face à la station correspondante en respectant une logique d'accessibilité au maximum pour sentir l'étiquette correspondante à la station au toucher. 
- Positionner aussi la légende et le triangle qui indique le nord

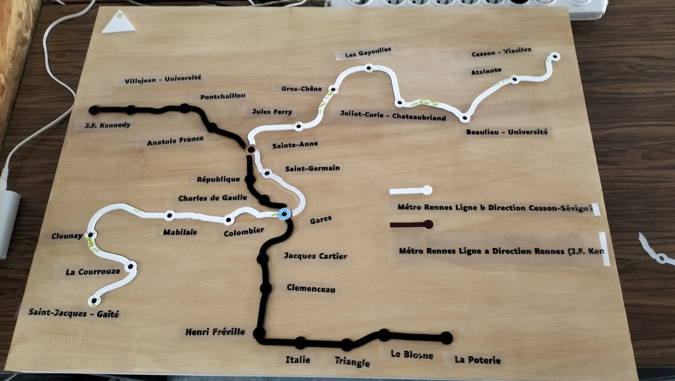
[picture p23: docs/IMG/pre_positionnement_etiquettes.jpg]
Prépositionnement étiquettes, légendes et triangle pour indiquer le Nord

*Prépositionnement étiquettes, légendes et triangle pour indiquer le Nord*

Une fois validé la position des étiquettes, les retirer et les conserver dans une boîte avec les éléments de la légende et le triangle. 

### Schéma de principe du cablage

* Alimentation 12V => Buck DC 5V & Amplificateur
* Buck DC 5V USB => USB alimentation du Raspberry Pi
* Raspberry PI USB  => shapeless_rp2040_40keys
* Sortie audio raspi => entrée ligne Amplificateur 
* Amplificateur Sortie HP => Haut Parleur

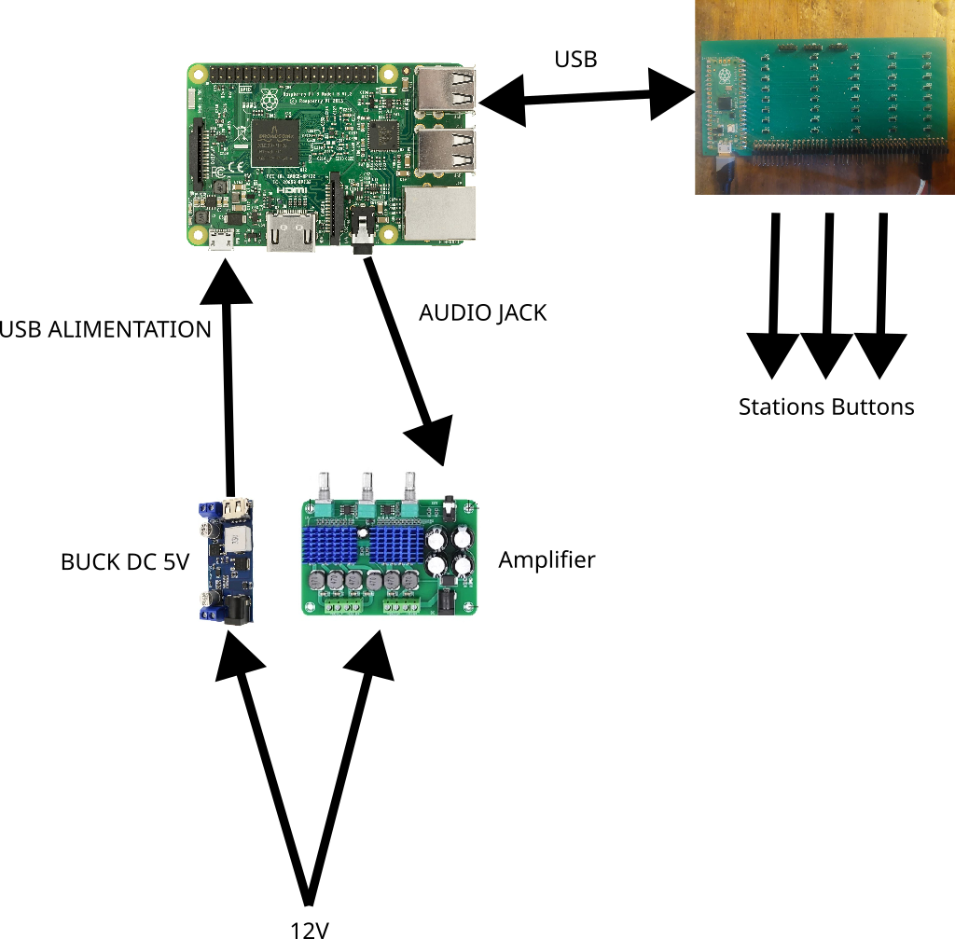
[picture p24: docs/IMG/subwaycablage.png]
Schema de principe


### Positionner la carte clavier et la coller

* Retourner le plan et positionner de manière provisoire la carte clavier dans l'espace libre et assurez-vous que les connecteurs de chaque boutons puissent l'atteindre
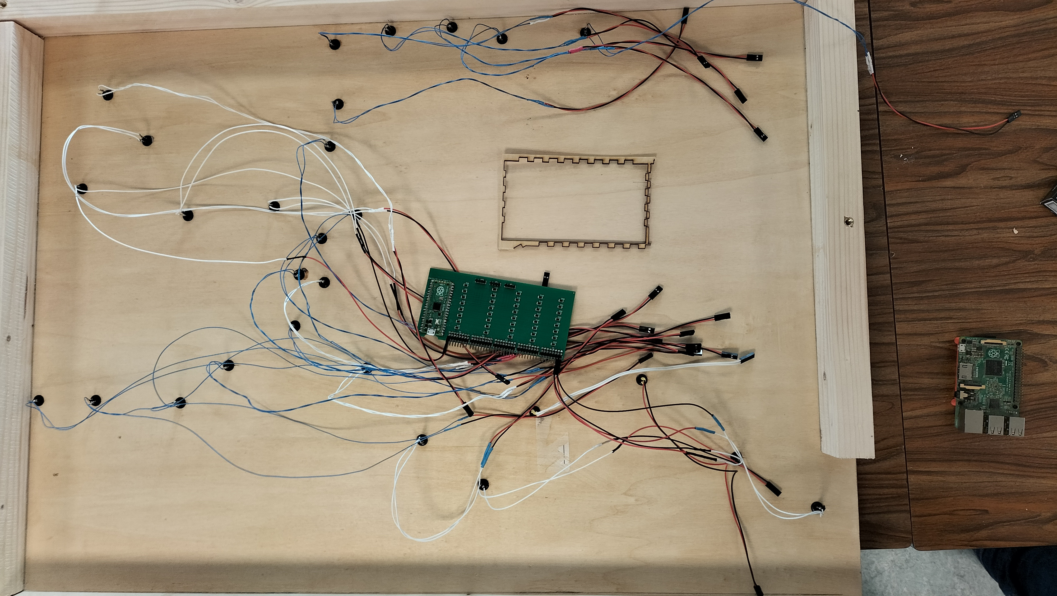
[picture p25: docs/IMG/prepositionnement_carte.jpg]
Prépositionnement carte clavier opur vérifier que chaque bouton puisse être connecté

*Prépositionnement carte clavier pour vérifier que chaque bouton puisse être connecté*

* Coller la carte clavier en ajoutant un cadre en bois que vous pouvez réaliser à la laser (sur la photo on a trouvé en récup quelque chose de convenable !) avec un pistolet à colle
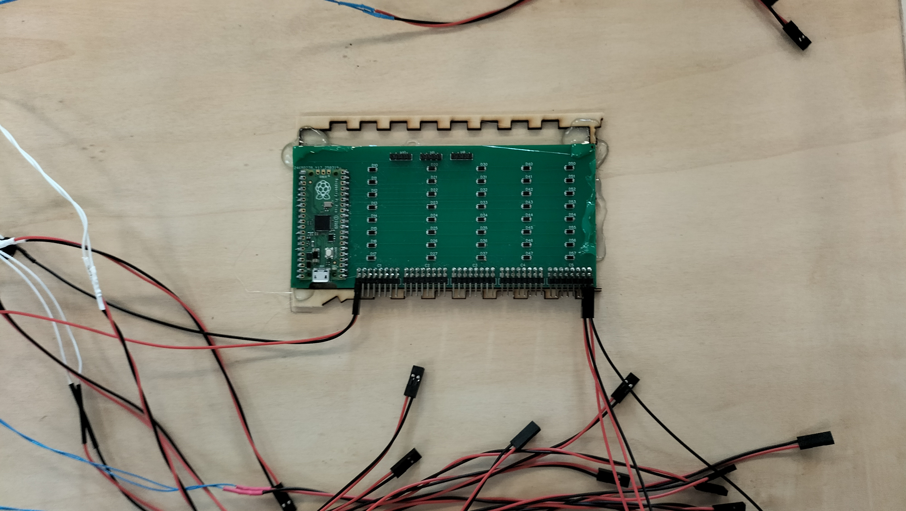
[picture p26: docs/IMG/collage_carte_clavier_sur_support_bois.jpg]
Collage de la carte clavier avec pistolet à colle


### Connecter les connecteurs de chaque bouton à la carte clavier
- Connecter les connecteurs des boutons si possible dans l'ordre des stations de la ligne pour faciliter le repérage mais ce n'est pas obligatoire!
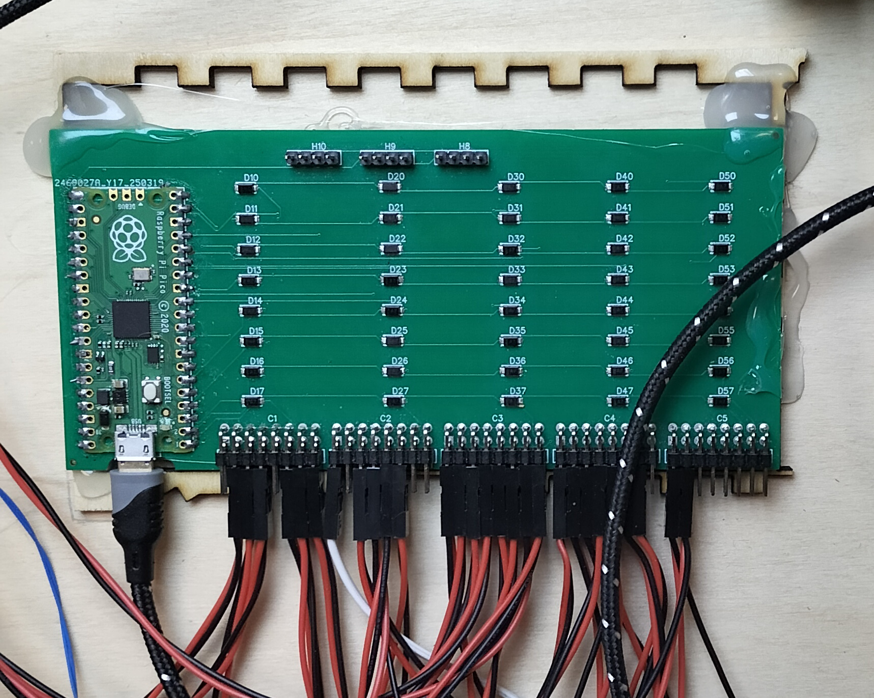
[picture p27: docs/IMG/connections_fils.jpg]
Connection des connecteurs des boutons à la carte clavier


### Regrouper les fils 
- Regrouper les fils et les fixer ensemble avec des collier de serrage (colsons)

### Assemblage de l'ensemble du montage électronique
- Le support imprimé en 3D, pour sortie de câble alimentation vers l'extérieur est vissé de part et d'autre sur les tasseaux
- L'ampli est collé avec deux ou 3 points de colle chaude au pistolet à colle
- Le passe câble speaker, le speaker, le convertisseur de tension et le domino sont fixés aussi au pistolet à colle
- Le support de la raspi imprimé en 3D est collé sur la plaque et le raspi est vissé sur le support.

- Le passe câble est utilisé ici pour passer le câble du haut-parleur (speaker) afin qu'il ne soit trop près du câble d'alimentation et du reste pour éviter les parasites.

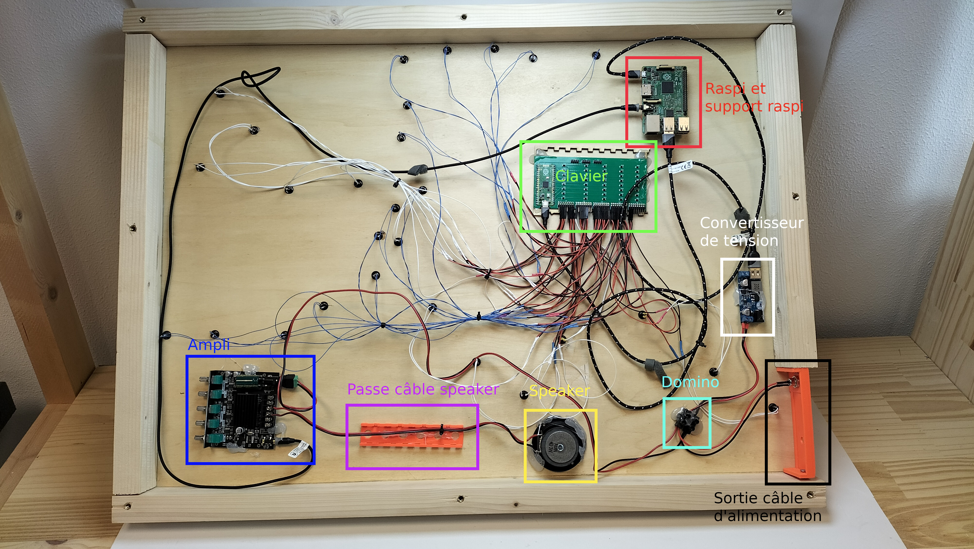
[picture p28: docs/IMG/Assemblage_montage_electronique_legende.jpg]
Assemblage du montage électronique

*Assemblage du montage électronique avec légende sur chacun des éléments*

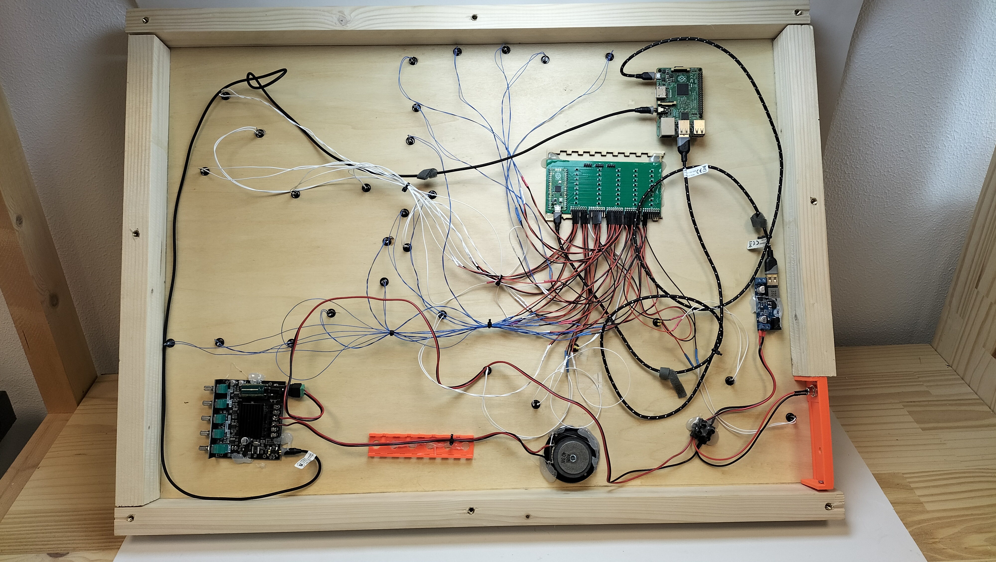
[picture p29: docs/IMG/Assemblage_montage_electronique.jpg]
Assemblage du montage électronique

*Assemblage du montage électronique*

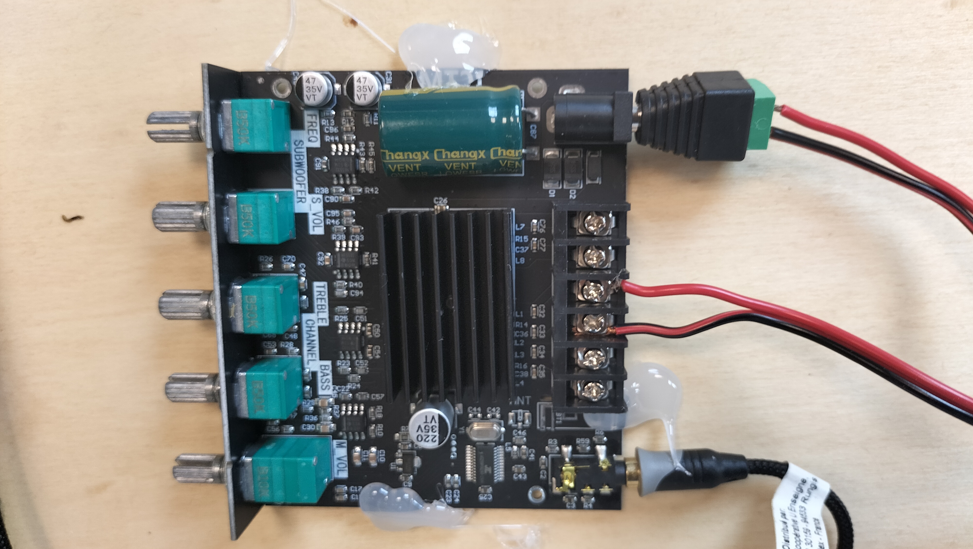
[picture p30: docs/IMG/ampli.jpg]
Ampli collé avec pistolet à colle

*Ampli collé avec pistolet à colle*

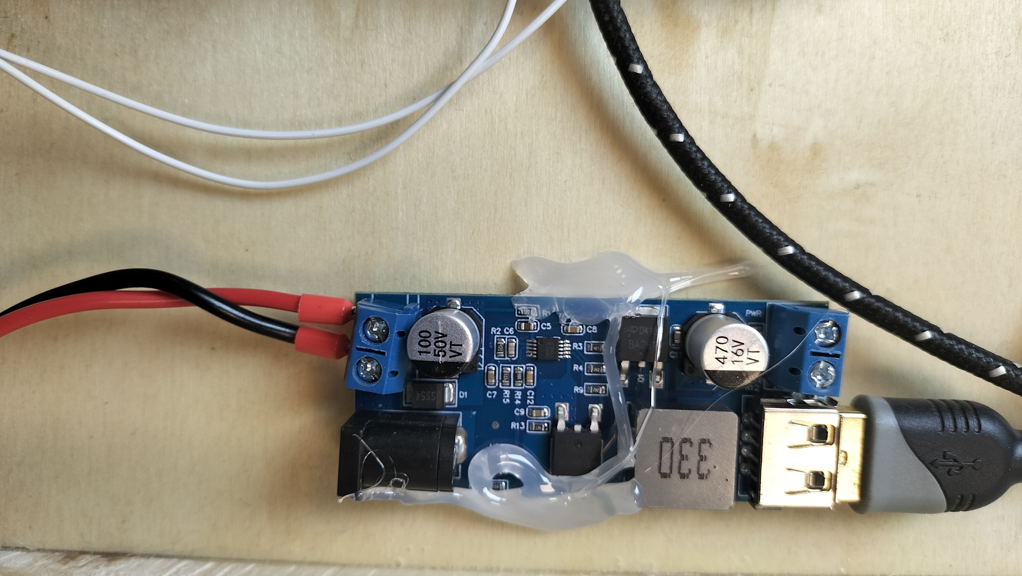
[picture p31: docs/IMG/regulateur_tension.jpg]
Régulateur de tension

*Régulateur de tension collé avec le pistolet à colle*

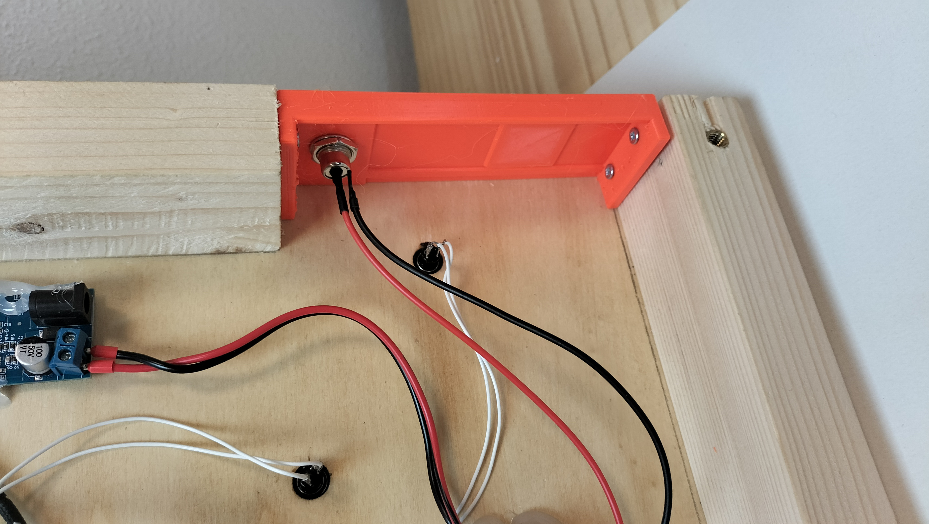
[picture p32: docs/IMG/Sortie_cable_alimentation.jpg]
Sortie de cable d'alimentation

*Sortie de câble d'alimentation imprimé en 3D*

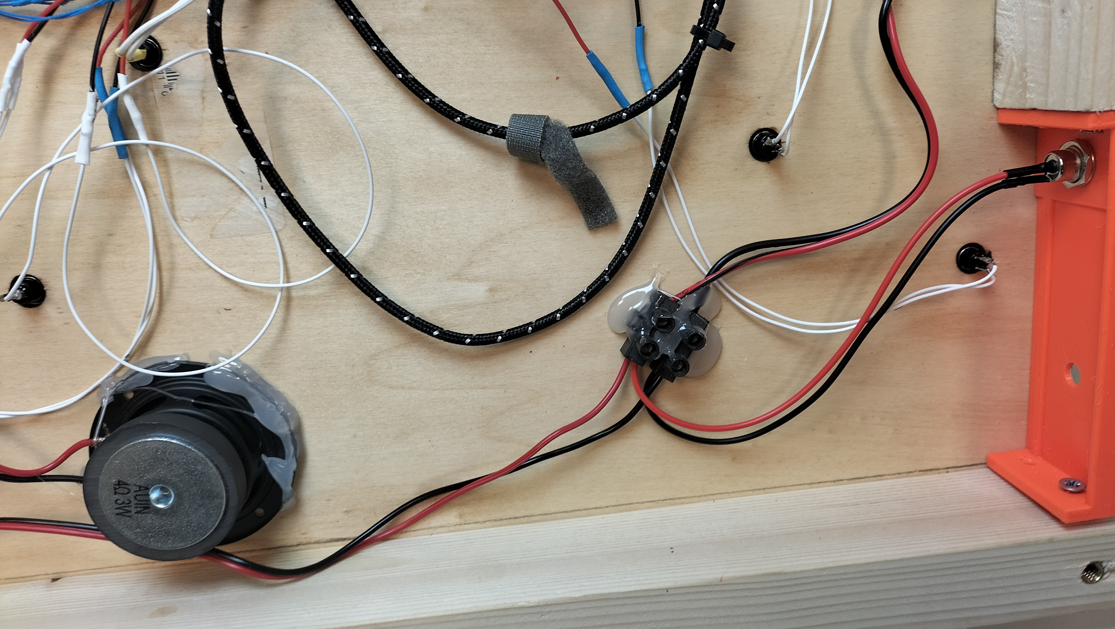
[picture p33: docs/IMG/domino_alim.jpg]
Domino d'alimentation

*Domino d'alimentation*

## Collage des étiquettes, légendes, et triangle
- Vérifier une dernière fois que vous avez bien l'ensemble des étiquettes en les positionnant à leurs emplacements
- Placer les légendes 
- Prendre une photo lorsque l'ensemble est cohérent, essayer de mettre les étiquettes d'une même ligne du même côté quand cela est possible
- Enlever les étiquettes
- Avec la colle en spray, coller une à une les étiquettes  
- Coller les légendes et ajouter les boutons en les reliant au circuit comme pour les stations, coller leur étiquette respective

## Vue d'ensemble du prototype final
Le montage est terminé :) 

Brancher le câble d'alimentation et expérimentez votre prototype avec des personnes déficientes visuelles ! Notez leurs retours et partagez-les nous !

Vue d'ensemble du prototype final
*Vue d'ensemble du prototype final*

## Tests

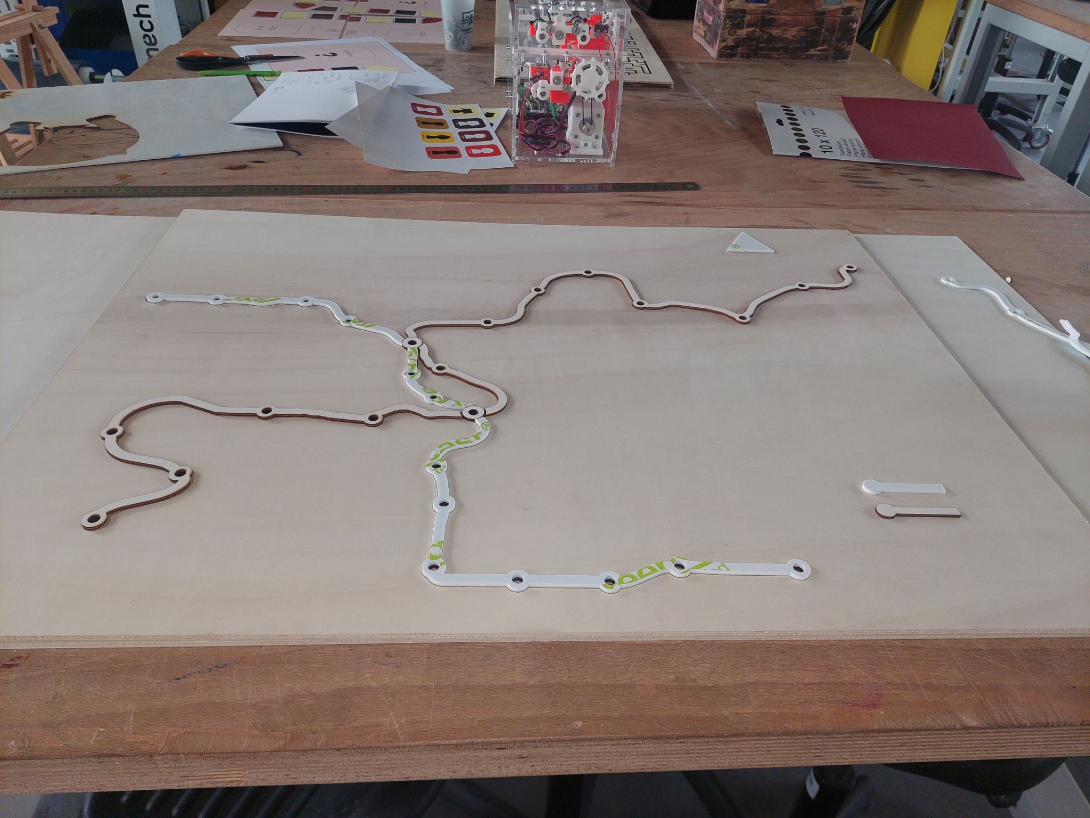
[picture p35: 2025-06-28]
docs/IMG/test_decoupe2.jpg

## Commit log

2025-06-23 add étapes de fabrication
2025-06-23 create étapes de fabrications.md
2025-06-23 remove étapes de fabrication
2025-06-23 add Transformation des fichiers
2025-06-23 added "etapes de fabrication" in index
2025-06-27 add titles inside Transformation des fichiers avec Inkscape
2025-06-27 add chapter Fabrication du plan de létro et Montage du circuit électronique
2025-06-27 correction préparationd es éléments pour la découpe laser
2025-06-27 chgt titre fabrication plan de métro avec son chassis
2025-06-27 add positionner carte clavier et la coller
2025-06-28 update BOM
2025-06-28 update laser prep
2025-06-28 plaque de fond
2025-06-28 lasercut lines prep
2025-06-28 refactoring BOM
2025-06-28 add 3d print
    [chemin_cable v4.step, chemin_cable.stl, subwaycommande v3.step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]
2025-06-28 add laser cut test image
2025-06-29 3d print added
    [support_rpi.stl]
2025-06-29 3d print
2025-06-30 add CAD for 3d print
    [support_rpi v3.step]
2025-06-30 add assemblage ensemble electro
2025-06-30 Assemblage de l'ensemble du montage électronique
2025-06-30 add img assemblage electro
2025-06-30 img assemblage electro avec légendes
2025-06-30 add assemblage et légende english
2025-06-30 assemblage electro étapes
2025-06-30 Translated using Weblate (English)
    Currently translated at 100.0% (2 of 2 strings)
    Translation: OpenStreetTangible_buildingmanual/manual_index
    Translate-URL: https://translate.codeberg.org/projects/openstreettangible_buildingmanual/manual_index/en/
2025-06-30 Translated using Weblate (English)
    Translation: OpenStreetTangible_buildingmanual/manual_licence
    Translate-URL: https://translate.codeberg.org/projects/openstreettangible_buildingmanual/manual_licence/en/
    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
2025-06-30 Translated using Weblate (English)
    Currently translated at 41.0% (16 of 39 strings)
    Translation: OpenStreetTangible_buildingmanual/manual_rpi_config
    Translate-URL: https://translate.codeberg.org/projects/openstreettangible_buildingmanual/manual_rpi_config/en/
2025-06-30 Translated using Weblate (English)
    Currently translated at 100.0% (6 of 6 strings)
    Translation: OpenStreetTangible_buildingmanual/manual_sourcecode
    Translate-URL: https://translate.codeberg.org/projects/openstreettangible_buildingmanual/manual_sourcecode/en/
2025-06-30 Translated using Weblate (English)
    Currently translated at 100.0% (39 of 39 strings)
    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
2025-06-30 Translated using Weblate (English)
    Currently translated at 6.5% (14 of 214 strings)
    Translation: OpenStreetTangible_buildingmanual/manual_building_step
    Translate-URL: https://translate.codeberg.org/projects/openstreettangible_buildingmanual/manual_building_step/en/
2025-06-30 Translated using Weblate (English)
    Currently translated at 25.7% (55 of 214 strings)
    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
2025-06-30 Translated using Weblate (English)
    Currently translated at 33.6% (72 of 214 strings)
    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
2025-06-30 Translated using Weblate (English)
    Currently translated at 26.3% (5 of 19 strings)
    Translation: OpenStreetTangible_buildingmanual/manual_manuel_utilisateur
    Translate-URL: https://translate.codeberg.org/projects/openstreettangible_buildingmanual/manual_manuel_utilisateur/en/
2025-06-30 Translated using Weblate (English)
    Currently translated at 100.0% (19 of 19 strings)
    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
2025-06-30 Translated using Weblate (English)
    Currently translated at 50.4% (108 of 214 strings)
    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
2025-06-30 Translated using Weblate (English)
    Currently translated at 89.7% (192 of 214 strings)
    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
2025-06-30 Translated using Weblate (English)
    Currently translated at 100.0% (214 of 214 strings)
    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
2025-07-01 orthographic corrections, add steps collage etiquettes et percage plaque fond et tasseaux pour inserts
2025-07-01 Translated using Weblate (English)
    Currently translated at 100.0% (233 of 233 strings)
    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
2026-03-14 Translated using Weblate (English)
    Currently translated at 100.0% (21 of 21 strings)
    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
